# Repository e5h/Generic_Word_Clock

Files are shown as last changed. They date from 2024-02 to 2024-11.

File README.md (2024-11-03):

# Generic Word Clock

## Summary

This repository contains the mechanical, electrical, and software components for a generic and customizable word clock.

All of these components can be used together to create a personalized version, or they can be used interchangeably with existing word clocks and controllers.

This is based on the original word clock project I did in 2017 ([Instructables](https://www.instructables.com/Minimalist-3D-Printed-RGB-Word-Clock/), [GitHub](https://github.com/e5h/Word-Clock)). I created an additional mechanical word clock meant to use much cheaper and easier to assemble LED strips ([Thingiverse](https://www.thingiverse.com/thing:3011627)) based on initial feedback, but both versions were lacking.

This "Generic" version is meant to be a direct replacement and upgrade for both. There is a custom controller based on an ESP32C3 module, much better software, and a more customizable mechanical design which includes a script to automatically generate a clock face with any installed font and combination of characters.

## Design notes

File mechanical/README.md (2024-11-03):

# Word Clock Mechanical Components (WIP)

## Summary

<div style="display: flex; gap: 0px;">
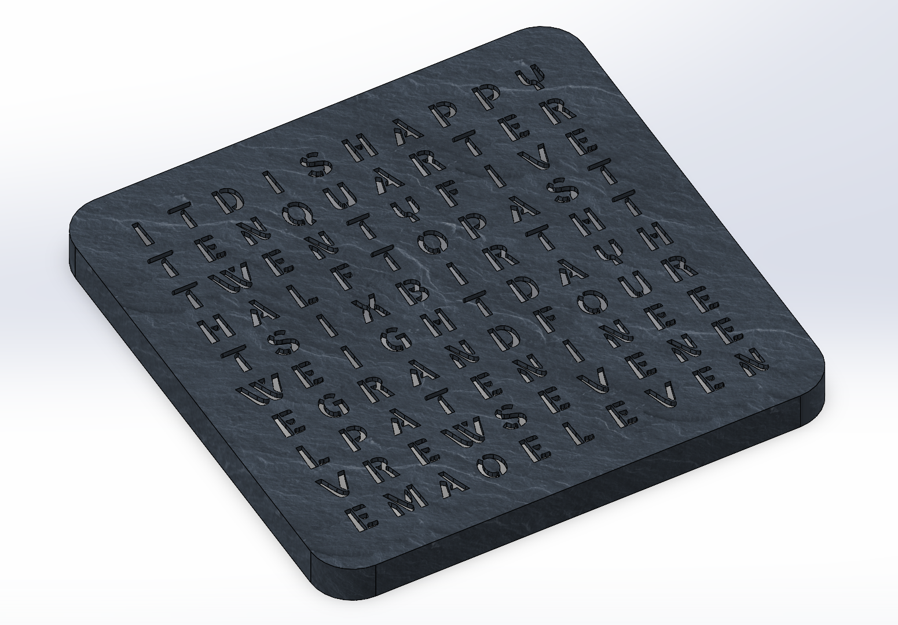
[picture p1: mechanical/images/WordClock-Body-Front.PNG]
Controller Front
  
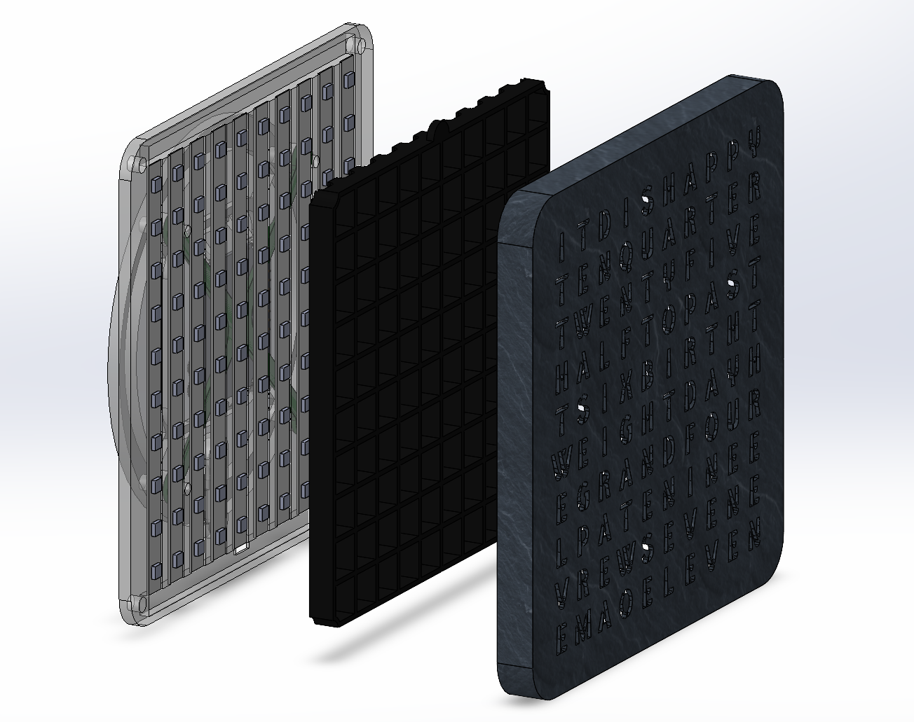
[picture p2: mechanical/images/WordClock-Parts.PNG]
  
</div>

<div style="display: flex; gap: 0px;">
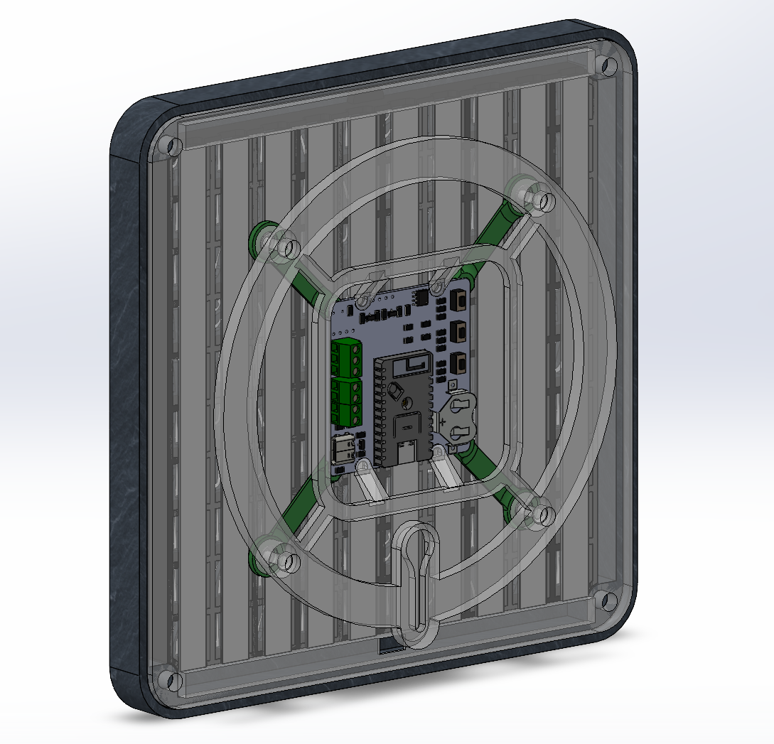
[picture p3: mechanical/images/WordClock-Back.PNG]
  
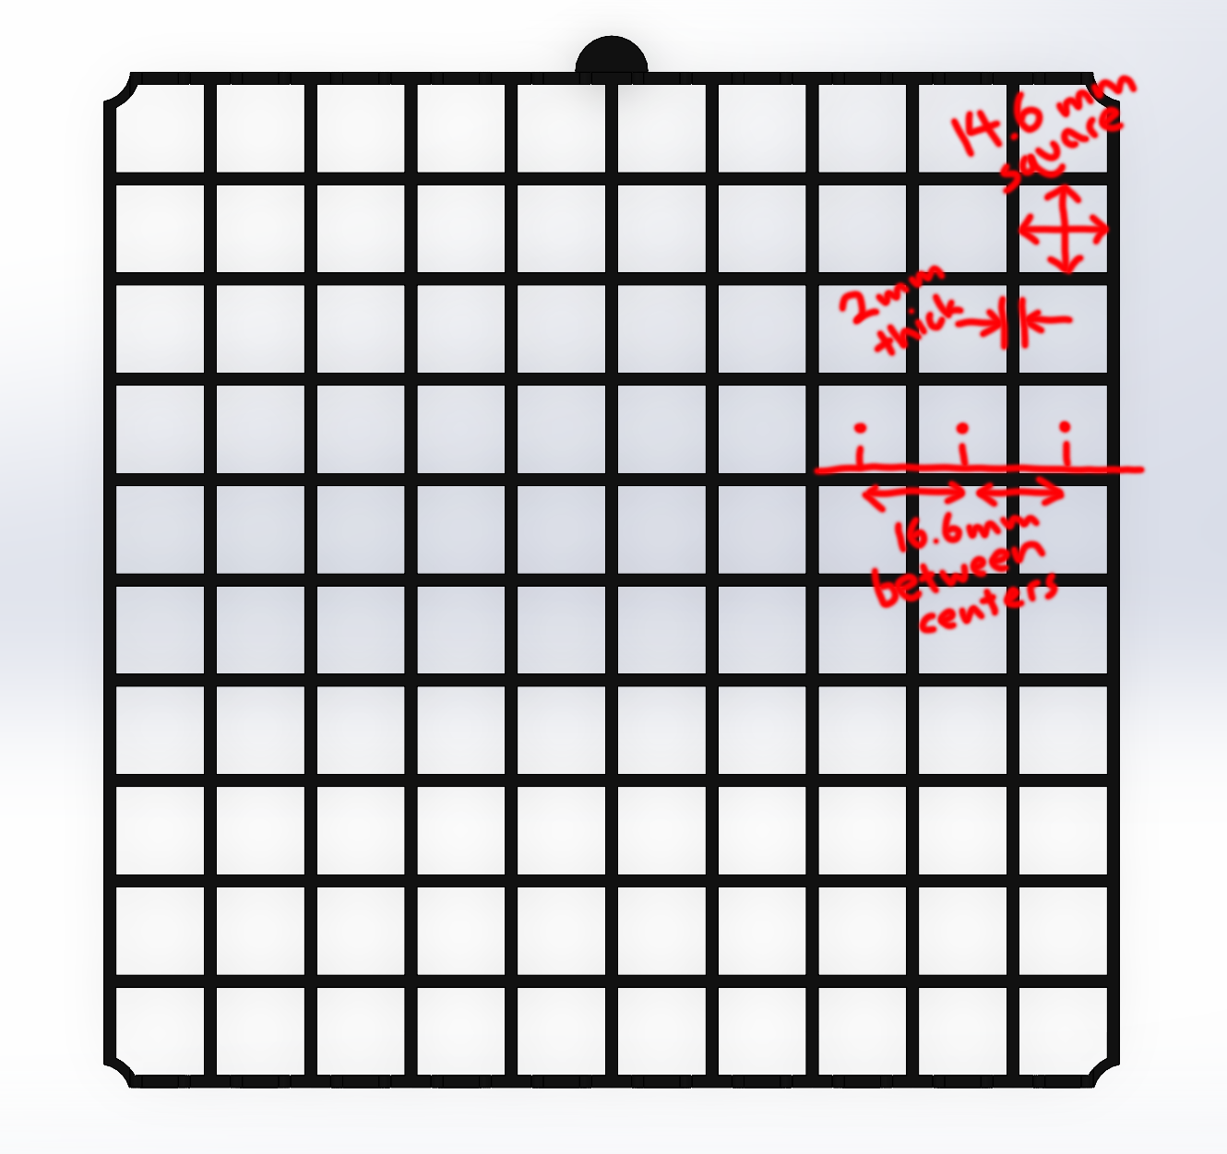
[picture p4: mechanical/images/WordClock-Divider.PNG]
  
</div>

The word clock uses a 3D printed body, with an RGB LED strip cut into pieces and glued to a back plate.

## Required Parts

| Part | Qnty. | Description | Supplier |
| --- |---| --- | --- |
| LED Strip | 1 | WS2812B (or similar) 60 LED / meter strip | [Amazon #1](https://www.amazon.ca/BTF-LIGHTING-Individual-Addressable-60Pixels-Non-Waterproof/dp/B088BPGMXB), [Amazon #2](https://www.amazon.ca/gp/product/B014R5PC42) |
| M3 Heat Set Nuts | 4 | Brass threaded nuts, buy a kit | [Amazon #3](https://www.amazon.ca/Assortment-Premium-Threaded-Embedment-Printing/dp/B0CTDBXGCF) |
| M4 Heat Set Nuts | 4 | Brass threaded nuts, buy a kit | [Amazon #3](https://www.amazon.ca/Assortment-Premium-Threaded-Embedment-Printing/dp/B0CTDBXGCF) |
| M3x8 Screw | 4 | Machine screw, any will do | [Amazon #4](https://www.amazon.ca/Hilitchi-510-Pcs-Button-Socket-Assortment/dp/B073SWNV5N) |
| M4x8 Screw | 4 | Button cap, but any will do | [Amazon #4](https://www.amazon.ca/Hilitchi-510-Pcs-Button-Socket-Assortment/dp/B073SWNV5N) |
| Hot Glue | n/a | For the LED strips / strain relief | n/a |
| Solder | n/a | Any | n/a |
| Wire | n/a | 3 conductor wire for LED strip to controller, 1 conductor for connections | n/a |
| USB-C Charging Cable | 1 | Slim right angle cable works best | [Amazon #5](https://www.amazon.ca/Agtray-4-Pack-Braided-Compatible-Samsung/dp/B0B6B7NK35) |
| USB Power Supply | 1 | \>5W properly rated supply | [Digikey](https://www.digikey.ca/en/products/detail/qualtek/QFWC-10-05/9771106) |

## 3D Printing

Note: Using a translucent filament color for the back panel and mount causes a nice backlight / glow effect on the mounting surface.

Note: Using a textured print plate will apply the textures to the clock face.

* Choose a darker filament for the clock body (or print solid infill) to prevent light transmission.
* Print the divider in black filament, or another color with zero transmission at 2mm thickness.
* Material does not matter, PLA or PETG work fine.
* Use a smaller nozzle (0.4mm or less) for the clock body to preserve detail on the clock face.

## Running The Clock Creation Script

### Requirements

1. Install [OpenSCAD](https://openscad.org/downloads.html) on your computer.
   1. On Windows, ensure the installed folder is added to the system %PATH% variable.
2. Install Python on your computer
3. Install a compatible stencil font on your computer.
   1. On Windows, you need to right click "Install For All Users" for OpenSCAD to have access to it.
   2. There are two stencil fonts (free for all use) included in the `/free_fonts` folder.

### Generating

1. Modify the `make_clock_body.txt` file to reflect your clock configuration:
   1. (TODO: unsupported) Add the font
   2. (TODO: unsupported) Add the text size
   3. Add the character layout
2. Run the `make_clock.py` script using Python and wait for completion.
3. Use the `Custom_Body.stl` file as your clock body.

#### Troubleshooting

All of the requirements need to be satisfied. The scripts do not perform sophisticated error checking and may not provide useful debug messages.

## DIY / Custom Solution

Creating a custom clock body (or using an existing one) is completely supported.

(TODO: more info)

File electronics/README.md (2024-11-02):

# Word Clock Electronics

## Summary

<div style="display: flex; gap: 10px;">
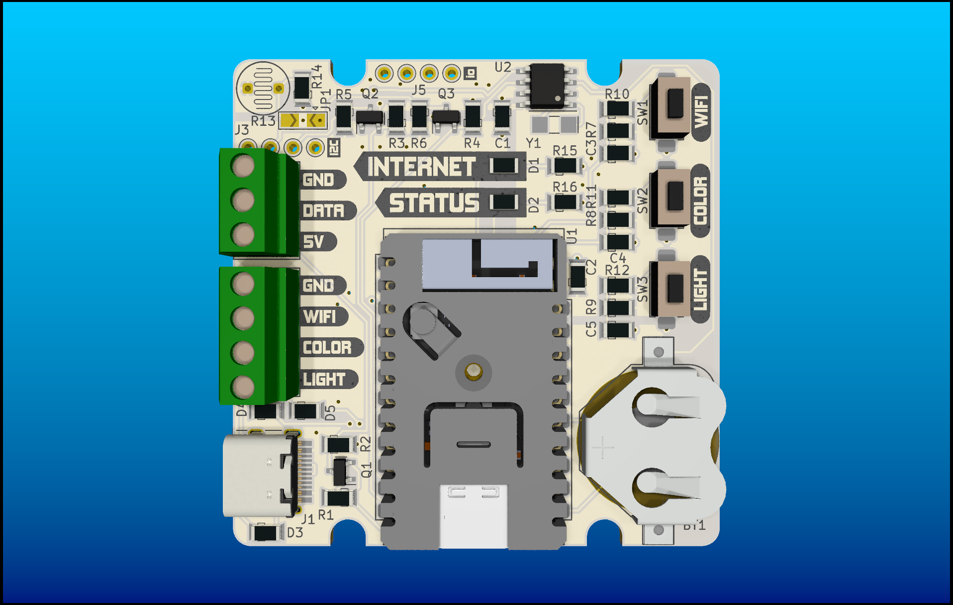
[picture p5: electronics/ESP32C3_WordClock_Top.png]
Controller Front
  
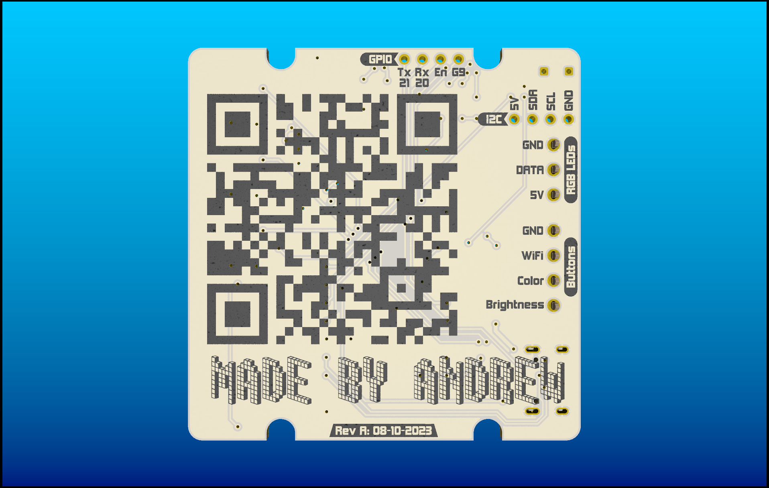
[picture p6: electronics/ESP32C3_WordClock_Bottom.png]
Controller Back
  
</div>

The word clock is powered by a custom ESP32-C3 based controller, using a PCF85263A real time clock module and a CR1632 backup battery.

The board was designed to use inexpensive parts, and has a small form factor which is inexpensive to get manufactured by online PCB fabricators. All components can be soldered by hand, and the back is unpopulated which allows using a hotplate and solder paste.

## Bill of Materials

| Ref | Type | Qnty | Part Number | Part Description | Supplier |
| --- | --- | ---- | --- | --- | ---|
| BT1 | Battery Holder  | 1 | 3012TR | CR1632 battery holder | [Digikey](https://www.digikey.ca/en/products/detail/keystone-electronics/3012TR/1978698) |
| C1 | Capacitor | 1 | 0.1uF-1uF | 0603-1206 X7R capacitor | |
| C2 | Capacitor | 1 | 0.1uF-1uF | 0603-1206 X7R capacitor | |
| C3, C4, C5 | Capacitor | 3 | 0.1uF | 0603-1206 X7R capacitor | |
| D1 | LED | 1 | SMD LED | 0603-1206 SMD LED | |
| D2 | LED | 1 | SMD LED | 0603-1206 SMD LED | |
| D3, D4, D5 | Diode | 3 | CUS520,H3F | External button protection diode | [Digikey](https://www.digikey.ca/en/products/detail/toshiba-semiconductor-and-storage/CUS520-H3F/5114303) |
| J1 | USB-C Conn. | 1 | USB4105-GF-A | USB_C_Receptacle_USB2.0 | [Digikey](https://www.digikey.ca/en/products/detail/gct/USB4105-GF-A/11198441) |
| J2 | Screw Terminal  | 1 | EBWA-03-A | External RGB LED connector | [Digikey](https://www.digikey.ca/en/products/detail/adam-tech/EBWA-03-A/9830974) |
| J3 | Empty Headers | 1 | n/a | 2.54mm external I2C breakout | |
| J4 | Screw Terminal  | 2 | EBWA-02-A | External buttons connector | [Digikey](https://www.digikey.ca/en/products/detail/adam-tech/EBWA-02-A/9830631) |
| J5 | Empty Headers | 1 | n/a | 2.54mm GPIO breakout | |
| JP1 | Jumper | 1 | n/a | Brightness select jumper | |
| Q1, Q2, Q3 | N-MOSFET | 3 | DMG2302UKQ-7 | Level shifter mosfet | [Digikey](https://www.digikey.ca/en/products/detail/diodes-incorporated/DMG2302UKQ-7/9769911) |
| R1, R2 | Resistor | 2 | 2.2kR | 0603-1206 SMD resistor, signal pullup | |
| R3, R5 | Resistor | 2 | 2.2kR | 0603-1206 SMD resistor, signal pullup | |
| R4, R6 | Resistor | 2 | 2.2kR | 0603-1206 SMD resistor, signal pullup | |
| R7, R8, R9, R14  | Resistor | 4 | 10kR | 10kR 0603-1206 SMD resistor | |
| R10, R11, R12 | Resistor | 3 | 1kR | 1kR 0603-1206 SMD resistor | |
| R13 | Photoresistor | 1 | varies | Generic THT photoresistor | |
| R15, R16 | Resistor | 2 | varies | LED resistors, size to D1 and D2 | |
| SW1 | Button | 1 | PTS636 SL43 SMTR LFS | WIFI push button | [Digikey](https://www.digikey.ca/en/products/detail/c-k/PTS636-SL43-SMTR-LFS/10071722) |
| SW2 | Button | 1 | PTS636 SL43 SMTR LFS | Color push button | [Digikey](https://www.digikey.ca/en/products/detail/c-k/PTS636-SL43-SMTR-LFS/10071723) |
| SW3 | Button | 1 | PTS636 SL43 SMTR LFS | Brightness push button | [Digikey](https://www.digikey.ca/en/products/detail/c-k/PTS636-SL43-SMTR-LFS/10071722) |
| U1 | Microcontroller | 1 | K056 | M5Stamp ESP32C3 module | [Digikey](https://www.digikey.ca/en/products/detail/m5stack-technology-co-ltd/K056/15667527) |
| U2 | RTC | 1 | PCF85263AT/AJ | Real time clock | [Digikey](https://www.digikey.ca/en/products/detail/nxp-usa-inc/PCF85263AT-AJ/5170041) |
| Y1 | Crystal | 1 | CM315D32768HZFT | 32.768kHz 12.5pF crystal | [Digikey](https://www.digikey.ca/en/products/detail/citizen-finedevice-co-ltd/CM315D32768HZFT/5970266) |

### Notes

- The footprints on the board for simple components are designed to work for 0603, 0805, and 1206 footprints (0402 may work for the brave). There are no specific part numbers listed.
- The resistor values for the LEDs, photoresistor, and the signal pullups can all be modified depending on need. 2.2kR for the signal pullups works well.

## DIY / Custom Solution

The firmware will work for any custom board (possibly a breadboard too) as long as the connections are the same as those listed in the schematic.

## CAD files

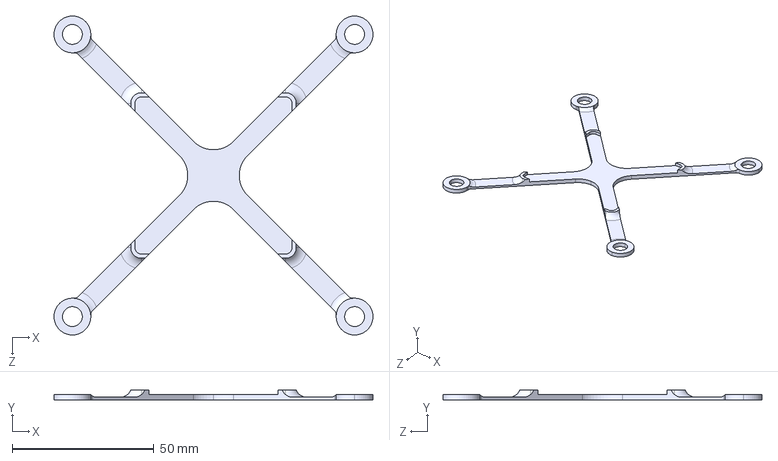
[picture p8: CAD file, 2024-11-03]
mechanical/Generic_Support_BoardHolder.STEP
112.6 x 3.50 x 112.6 mm

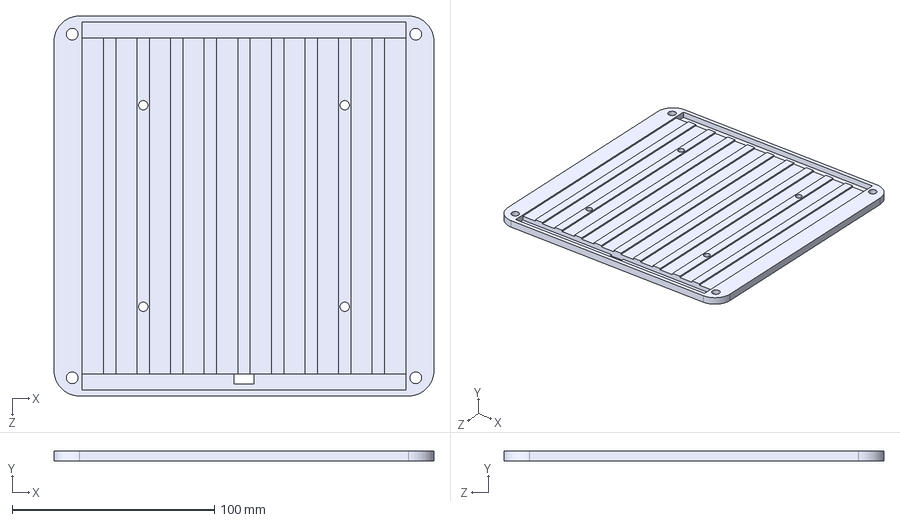
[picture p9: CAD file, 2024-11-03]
mechanical/Generic_Backplate.STEP
187.8 x 5.00 x 187.8 mm

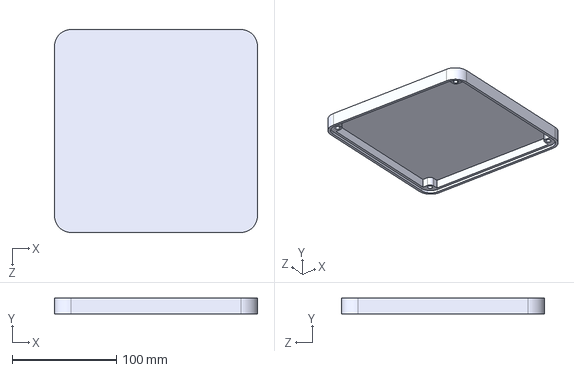
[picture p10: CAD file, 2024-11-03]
mechanical/Generic_Body_NoText.STEP
194.6 x 15.0 x 194.6 mm

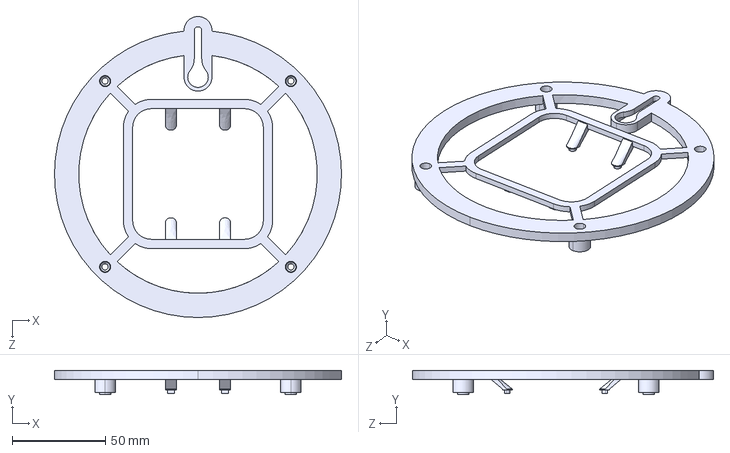
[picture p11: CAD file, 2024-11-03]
mechanical/Generic_Support_WallMount.STEP
153.9 x 13.0 x 161.4 mm

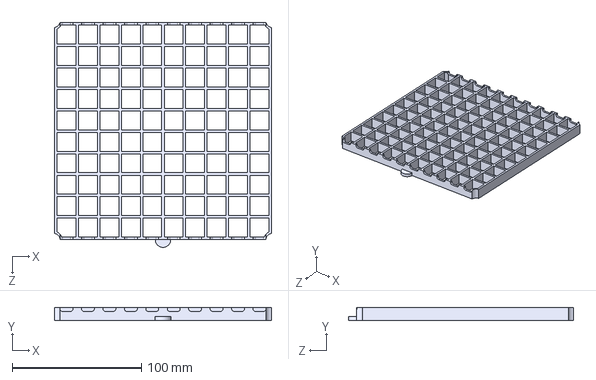
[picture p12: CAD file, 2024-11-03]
mechanical/Generic_Divider.STEP
168.0 x 10.0 x 174.0 mm

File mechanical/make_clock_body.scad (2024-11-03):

/* Variables */

// This is a default layout. Override it with a script.
ARG_clock_layout = [
  ["I", "T", "U", "I", "S", "J", "A", "X", "M", "Y"],
  ["T", "W", "E", "N", "T", "Y", "H", "A", "L", "F"],
  ["H", "A", "P", "P", "Y", "H", "F", "I", "V", "E"],
  ["T", "E", "N", "Q", "U", "A", "R", "T", "E", "R"],
  ["T", "O", "P", "A", "S", "T", "B", "D", "A", "Y"],
  ["O", "N", "E", "F", "O", "U", "R", "T", "W", "O"],
  ["F", "I", "V", "E", "S", "I", "X", "T", "E", "N"],
  ["T", "H", "R", "E", "E", "S", "E", "V", "E", "N"],
  ["T", "W", "E", "L", "V", "E", "I", "G", "H", "T"],
  ["N", "I", "N", "E", "L", "E", "V", "E", "N", "J"]
];

/*
Requires a stencil-type font (no closed off areas)

Some good options:
"CF StencilOrama" (personal use only)
"Crevice Stencil" (personal use only)
"Qawine Again" (personal use only)
"WC Wunderbach BTA"
"Secrets Stencil"
*/
ARG_font = "WC Wunderbach BTA";
ARG_font_size = 12;

// Total width of the body (square)
clock_width = 194.6;//mm

// Thickness of the body
clock_thickness = 15.0;//mm

// Total width of the divider (square)
divider_width = 168.0;//mm

// Thickness of the divider walls
divider_wall_thickness = 2.0;//mm

// Spacing between characters
char_spacing = 16.6;//mm

// Character bound box
char_bound_box = 14.6;//mm

// Movement constants
text_cut_slop = 5;//mm

move_clock_x = -clock_width/2;
move_clock_y = clock_thickness;
move_clock_z = -clock_width/2;

move_all_text_offset = divider_wall_thickness + char_bound_box/2;
move_all_text_x = move_all_text_offset - (divider_width/2);
move_all_text_y = clock_thickness - text_cut_slop;
move_all_text_z = (divider_width/2) - move_all_text_offset;

/* Parts */

// Blank clock body
module blank_clock_body()
{
  translate([move_clock_x, move_clock_y, move_clock_z])
  {
    mirror([0, 1, 0])
    {
      import("Generic_Body_NoText.STL");
    }
  }
}

// Individual extruded character
module extruded_char(char)
{
  linear_extrude(height = clock_thickness + text_cut_slop)
  {
    text(
      char,
      font = ARG_font,
      size = min(ARG_font_size, char_bound_box - 2),
      halign = "center",
      valign = "center"
    );
  }
}

// Grid of all characters
module extruded_clock_chars()
{
  for (row = [0 : len(ARG_clock_layout) - 1])
  {
    for (col = [0 : len(ARG_clock_layout[row]) - 1])
    {
      translate([col*char_spacing, -row*char_spacing, 0])
      {
        extruded_char(ARG_clock_layout[row][col]);
      }
    }
  }
}

// The clock characters object
module clock_chars()
{
  translate([move_all_text_x, move_all_text_y, move_all_text_z])
  {
    rotate([90, 0, 0])
    {
      extruded_clock_chars();
    }
  }
}


/* Operations */

// Subtracting a text grid from the blank clock body
difference()
{
  // Blank clock body
  blank_clock_body();
  // Text object
  clock_chars();
}

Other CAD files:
mechanical/Generic_Body_NoText.STL

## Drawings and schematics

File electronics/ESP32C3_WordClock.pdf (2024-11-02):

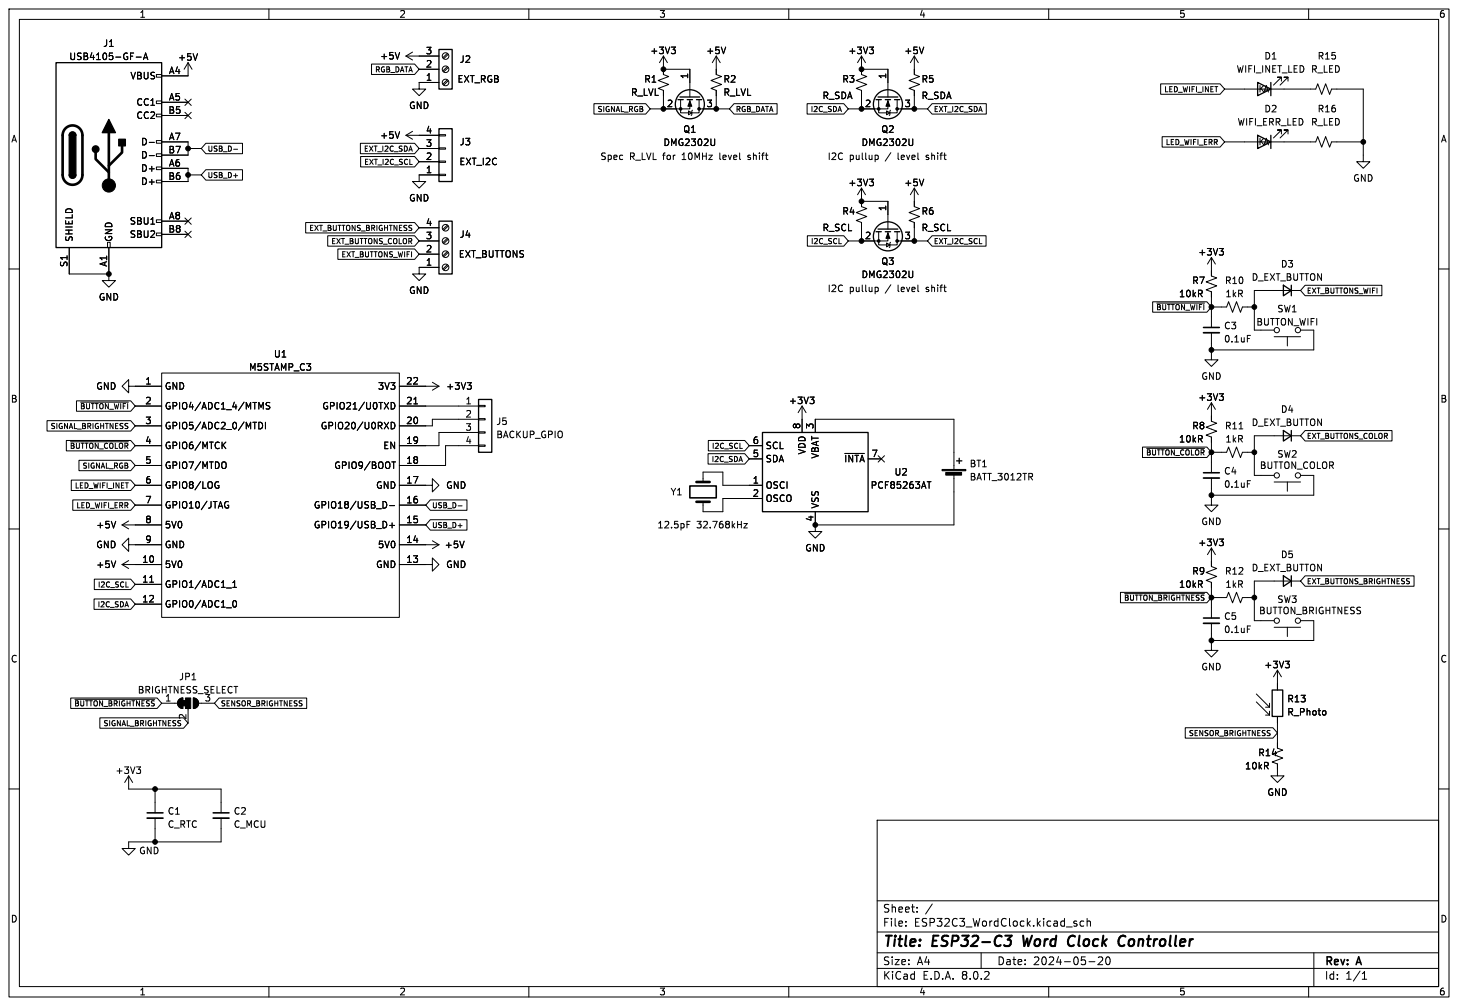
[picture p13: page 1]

Spec R_LVL for 10MHz level shift

4 SDA 5 SCL 6 ~{INTA} VDD 7

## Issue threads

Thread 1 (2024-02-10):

Add button functionality

e5h, 2024-02-10:
Read from the four buttons on the controller board, and support additional features:

- Abstracted button read (interrupts, i2c expander, gpio)
- Per-button state machine supporting press, hold, repeat
- Queue messaging according to pub/sub architecture

e5h, 2024-02-11:
Requires #6 to be completed before the send functionality can be added

Closed 2024-02-18.

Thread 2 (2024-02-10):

Implement real time clock

e5h, 2024-02-10:
Need to write a driver and functions for the embedded PCF8526 real time clock.

- Get time, set time
- Test battery backup
- Use NVS and timestamps to test for dead battery

e5h, 2024-05-21:
Major functionality is implemented, but needs to be tested to ensure it works with the time library, and with the hardware.

1. Ensure the conversions to and from timestamp structures are correct
2. Ensure the i2c bus is working correctly
3. Ensure the RTC has time set properly
4. Ensure the RTC battery backup is working as expected

e5h, 2024-07-14:
See comment for #[6db955e](https://github.com/e5h/Generic_Word_Clock/commit/6db955ef784d77e764c517fdd5c030156d678ece)

Getting time and setting time works, and the RTC is functional. All registers have been defined if more complex logic is needed in the future. NVS is unnecessary for testing a dead battery, simply evaluate if the RTC has the default value stored on boot.

Further changes will be done in higher-level feature tickets.

e5h, 2024-07-14:
Merged in PR #10.

Closed 2024-07-14.

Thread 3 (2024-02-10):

Implement networking

e5h, 2024-02-10:
Need to implement a number of networking features:

- Wifi AP, using dns redirect to a hosted html page with various settings (separate issue)
- Wifi STA, periodically access ntp server to calibrate / update the RTC
- Fault tolerant state machines for wifi, ntp, http server
- (?) html page when connected as sta to wifi?

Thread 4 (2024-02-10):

Create i2c access controls

e5h, 2024-02-10:
Esp-idf does not have access controls for multiple devices using the i2c bus. Find an existing solution, or implement an access lock to prevent bus conflicts.

e5h, 2024-07-14:
Note: this is no longer true, the new version of ESP-IDF which I have upgraded to (IDF 5.2+) contain a new I2C driver (https://docs.espressif.com/projects/esp-idf/en/v5.2.2/esp32/api-reference/peripherals/i2c.html). This resolves the access control issues with the legacy driver, so there is no longer a need for i2c_manager.

Closed 2024-05-20.

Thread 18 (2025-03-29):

Add event system / architecture

e5h, 2025-03-29:
Functionality partially exists with the messaging system. There are a few different tasks running concurrently, and they all have unique state machines which should be influenced by the idea of "events" generating from other tasks.

Example:

1. Device task detects "wifi button" held, generates a "wifi button held" event
2. Network task receives "wifi button held" event, attempts to connect to wifi as sta
3. Network task detects successful connection, generates a "wifi sta connected" event
4. Device task should receive a "wifi sta connected" event, and toggle the "wifi LED"
5. Display task can indicate a wifi connection event (?)

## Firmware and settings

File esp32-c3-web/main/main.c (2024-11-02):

/*~*~*~*~*~*~*~*~*~*~*~*~*~*~*~*~*~*~*~*~*~*~*~*~*~*~*~*~*~*~*~*~*~*~*~*~*~*~*~*~
 * NAME:
 *      main.c
 *
 * PURPOSE:
 *      This is the main file for running the generic word clock.
 *
 * DEPENDENCIES:
 *      lib_includes.h
 *
 *~*~*~*~*~*~*~*~*~*~*~*~*~*~*~*~*~*~*~*~*~*~*~*~*~*~*~*~*~*~*~*~*~*~*~*~*~*~*~*
 * (C) Andrew Bright 2023, github.com/e5h
 *~*~*~*~*~*~*~*~*~*~*~*~*~*~*~*~*~*~*~*~*~*~*~*~*~*~*~*~*~*~*~*~*~*~*~*~*~*~*~*/

/*~*~*~*~*~*~*~*~*~*~*~*~*~*~*~*~*~*~*~*~*~*~*~*~*~*~*~*~*~*~*~*~*~*~*~*~*~*~*~*/
/*][ Include Files ][*~*~*~*~*~*~*~*~*~*~*~*~*~*~*~*~*~*~*~*~*~*~*~*~*~*~*~*~*~*/
/*~*~*~*~*~*~*~*~*~*~*~*~*~*~*~*~*~*~*~*~*~*~*~*~*~*~*~*~*~*~*~*~*~*~*~*~*~*~*~*/

#include <stdio.h>
#include "lib_includes.h"
#include "lib_messaging.h"

#include "rgb_rmt.h"
#include "cfg_clock.h"
#include "rtc.h"

#include "task_display.h"
// task device
// task network

#include "esp_timer.h"
#include "nvs_flash.h"

/*~*~*~*~*~*~*~*~*~*~*~*~*~*~*~*~*~*~*~*~*~*~*~*~*~*~*~*~*~*~*~*~*~*~*~*~*~*~*~*/
/*][ LOCAL : Constants and Types ][*~*~*~*~*~*~*~*~*~*~*~*~*~*~*~*~*~*~*~*~*~*~*/
/*~*~*~*~*~*~*~*~*~*~*~*~*~*~*~*~*~*~*~*~*~*~*~*~*~*~*~*~*~*~*~*~*~*~*~*~*~*~*~*/

typedef enum{
    FLAG_1_MS           = 0x01, /* Flag set on 1ms timer callback */
    FLAG_10_MS          = 0x02, /* Flag set on 10ms timer callback */
    FLAG_100_MS         = 0x04, /* Flag set on 100ms timer callback */
    FLAG_1_SEC          = 0x08, /* Flag set on 1s timer callback */
} E_THREAD_FLAG;

/*~*~*~*~*~*~*~*~*~*~*~*~*~*~*~*~*~*~*~*~*~*~*~*~*~*~*~*~*~*~*~*~*~*~*~*~*~*~*~*/
/*][ LOCAL : Variables ][*~*~*~*~*~*~*~*~*~*~*~*~*~*~*~*~*~*~*~*~*~*~*~*~*~*~*~*/
/*~*~*~*~*~*~*~*~*~*~*~*~*~*~*~*~*~*~*~*~*~*~*~*~*~*~*~*~*~*~*~*~*~*~*~*~*~*~*~*/

/* ESP event groups (flags) */
EventGroupHandle_t heartbeat_flags;

/* ESP timer handles */
esp_timer_handle_t timer_handle_1ms;
esp_timer_handle_t timer_handle_10ms;
esp_timer_handle_t timer_handle_100ms;
esp_timer_handle_t timer_handle_1sec;

/* FreeRTOS task handles */
TaskHandle_t h_task_heartbeat;

/* Order and request queues */
QueueHandle_t q_heartbeat_task;

// Clock configuration
static CLOCK_CONFIG clock_config_s;

/*~*~*~*~*~*~*~*~*~*~*~*~*~*~*~*~*~*~*~*~*~*~*~*~*~*~*~*~*~*~*~*~*~*~*~*~*~*~*~*/
/*][ LOCAL : Function Prototypes ][*~*~*~*~*~*~*~*~*~*~*~*~*~*~*~*~*~*~*~*~*~*~*/
/*~*~*~*~*~*~*~*~*~*~*~*~*~*~*~*~*~*~*~*~*~*~*~*~*~*~*~*~*~*~*~*~*~*~*~*~*~*~*~*/

/*~*~*~*~*~*~*~*~*~*~*~*~*~*~*~*~*~*~*~*~*~*~*~*~*~*~*~*~*~*~*~*~*~*~*~*~*~*~*~*/
/*][ Function Definitions ][~*~*~*~*~*~*~*~*~*~*~*~*~*~*~*~*~*~*~*~*~*~*~*~*~*~*/
/*~*~*~*~*~*~*~*~*~*~*~*~*~*~*~*~*~*~*~*~*~*~*~*~*~*~*~*~*~*~*~*~*~*~*~*~*~*~*~*/

/**===< local >================================================================
 * NAME:
 *      nvs_save_clock_config() - saves the current clock configuration
 *
 * SUMMARY:
 *      Takes all of the clock configuration values and saves them to non
 *      volatile storage.
 *
 * INPUT REQUIREMENTS:
 *      ---
 *
 * OUTPUT GUARANTEES:
 *      Returns an enum status (fail <= 0, success > 0)
 **===< local >================================================================*/
static STATUS_E nvs_save_clock_config( CLOCK_CONFIG* new_config_s )
{
    nvs_handle_t nvs_handle;
    size_t config_size = sizeof( CLOCK_CONFIG );

    esp_err_t err;
    STATUS_E status_e = STATUS_OK;

    // Check for differences to reduce memory wear
    if( memcmp( new_config_s, &clock_config_s, config_size ) == 0 )
    {
        return STATUS_NO_CHANGE; // No change
    }

    // TODO: Sanity check the values

    err = nvs_open( "clock", NVS_READWRITE, &nvs_handle );
    if( err != ESP_OK )
    {
        ESP_LOGE("nvs_save_clock_config", "Could not open NVS! (%s)", esp_err_to_name(err));
        return STATUS_ERR;
    }

    err = nvs_set_blob( nvs_handle, "clockconfig", new_config_s, config_size );
    if( err != ESP_OK )
    {
        ESP_LOGE("nvs_save_clock_config", "Could not write to NVS! (%s)", esp_err_to_name(err));
        return STATUS_ERR;
    }

    err = nvs_commit( nvs_handle );
    if( err != ESP_OK )
    {
        ESP_LOGE("nvs_save_clock_config", "Could not save NVS! (%s)", esp_err_to_name(err));
        return STATUS_ERR;
    }

    nvs_close( nvs_handle );
    ESP_LOGW("nvs_save_clock_config", "Saved clock config to NVS.");
    ESP_LOGI("nvs_save_clock_config", "Saved time: ");
    // TODO: Convert the struct tm to a readable timestamp.

    clock_config_s = *new_config_s;

    return status_e;
}

/**===< local >================================================================
 * NAME:
 *      nvs_load_clock_config() - loads the current clock configuration
 *
 * SUMMARY:
 *      Loads all of the clock configuration values from the on-board non
 *      volatile storage.
 *
 * INPUT REQUIREMENTS:
 *      ---
 *
 * OUTPUT GUARANTEES:
 *      Returns an enum status (fail <= 0, success > 0)
 **===< local >================================================================*/
static STATUS_E nvs_load_clock_config( CLOCK_CONFIG* new_config_s )
{
    nvs_handle_t nvs_handle;
    size_t config_size = sizeof( CLOCK_CONFIG );

    esp_err_t err;
    STATUS_E status_e = STATUS_OK;

    err = nvs_open( "clock", NVS_READWRITE, &nvs_handle );
    if( err != ESP_OK )
    {
        ESP_LOGE("nvs_load_clock_config", "Could not open NVS! (%s)", esp_err_to_name(err));
        return STATUS_ERR;
    }

    err = nvs_get_blob( nvs_handle, "clockconfig", new_config_s, &config_size );
    if( err != ESP_OK )
    {
        ESP_LOGE("nvs_load_clock_config", "Could not read from NVS! (%s)", esp_err_to_name(err));
        return STATUS_ERR;
    }

    err = nvs_commit( nvs_handle );
    if( err != ESP_OK )
    {
        ESP_LOGE("nvs_load_clock_config", "Could not save NVS! (%s)", esp_err_to_name(err));
        return STATUS_ERR;
    }

    nvs_close( nvs_handle );
    ESP_LOGW("nvs_load_clock_config", "Loaded clock config from NVS.");
    ESP_LOGI("nvs_load_clock_config", "Loaded time: ");
    // TODO: Convert the struct tm to a readable timestamp.

    clock_config_s = *new_config_s;

    return status_e;
}

/*~*~*~*~*~*~*~*~*~*~*~*~*~*~*~*~*~*~*~*~*~*~*~*~*~*~*~*~*~*~*~*~*~*~*~*~*~*~*~*~
 * Timer callback - 1 ms
 *
 * DESCRIPTION:
 *      This function is called every 1 millisecond. The purpose is to wake
 *      certain tasks periodically by setting their task notification bits.
 *~*~*~*~*~*~*~*~*~*~*~*~*~*~*~*~*~*~*~*~*~*~*~*~*~*~*~*~*~*~*~*~*~*~*~*~*~*~*~*/
void timer_1ms_callback(void *param)
{
    TIMER_TickMsUpdate(); /* Updates the 1ms tick inside lib_timer */
    //xEventGroupSetBits( heartbeat_flags, FLAG_1_MS );
}

/*~*~*~*~*~*~*~*~*~*~*~*~*~*~*~*~*~*~*~*~*~*~*~*~*~*~*~*~*~*~*~*~*~*~*~*~*~*~*~*~
 * Timer callback - 10 ms
 *
 * DESCRIPTION:
 *      This function is called every 10 milliseconds. The purpose is to wake
 *      certain tasks periodically by setting their task notification bits.
 *~*~*~*~*~*~*~*~*~*~*~*~*~*~*~*~*~*~*~*~*~*~*~*~*~*~*~*~*~*~*~*~*~*~*~*~*~*~*~*/
void timer_10ms_callback(void *param)
{
    // Set event group bits
}

/*~*~*~*~*~*~*~*~*~*~*~*~*~*~*~*~*~*~*~*~*~*~*~*~*~*~*~*~*~*~*~*~*~*~*~*~*~*~*~*~
 * Timer callback - 100 ms
 *
 * DESCRIPTION:
 *      This function is called every 100 milliseconds. The purpose is to wake
 *      certain tasks periodically by setting their task notification bits.
 *~*~*~*~*~*~*~*~*~*~*~*~*~*~*~*~*~*~*~*~*~*~*~*~*~*~*~*~*~*~*~*~*~*~*~*~*~*~*~*/
void timer_100ms_callback(void *param)
{
    xEventGroupSetBits(heartbeat_flags, FLAG_100_MS );
}

/*~*~*~*~*~*~*~*~*~*~*~*~*~*~*~*~*~*~*~*~*~*~*~*~*~*~*~*~*~*~*~*~*~*~*~*~*~*~*~*~
 * Timer callback - 1 sec
 *
 * DESCRIPTION:
 *      This function is called every 1 second. The purpose is to wake
 *      certain tasks periodically by setting their task notification bits.
 *~*~*~*~*~*~*~*~*~*~*~*~*~*~*~*~*~*~*~*~*~*~*~*~*~*~*~*~*~*~*~*~*~*~*~*~*~*~*~*/
void timer_1sec_callback(void *param)
{
    xEventGroupSetBits(heartbeat_flags, FLAG_1_SEC );
}

/*~*~*~*~*~*~*~*~*~*~*~*~*~*~*~*~*~*~*~*~*~*~*~*~*~*~*~*~*~*~*~*~*~*~*~*~*~*~*~*~
 * TASK: task_heartbeat
 * PRIO: 2 - default priority (runs constantly)
 *
 * DESCRIPTION:
 *      This task handles periodic behaviour, primarily for testing.
 *
 *~*~*~*~*~*~*~*~*~*~*~*~*~*~*~*~*~*~*~*~*~*~*~*~*~*~*~*~*~*~*~*~*~*~*~*~*~*~*~*/
void task_heartbeat(void* params )
{
    char* LOG_TAG = "task_heartbeat";

    EventBits_t new_msg_flag_s = 0x80u;
    MESSAGE_CONTENT_T rec_msg;
    MESSAGE_RECEIVER_T inbox = {
            &heartbeat_flags,
            new_msg_flag_s,
            q_heartbeat_task
    };

    EventBits_t flags_to_wait;
    flags_to_wait = FLAG_100_MS | FLAG_1_SEC | new_msg_flag_s;

    UINT8 active_leds[10] = {0}; // Index of which LEDs are active
    
    UINT8 colorIndex_UC = COLOR_Cyan;
    RGB_COLOR_PCT led_color = RGB_LED_default_colors_S[ colorIndex_UC ];

    MESSAGING_subscribe_to_topic(MSG_BUTTONS, &inbox);

    // Temporarily here for testing
    BUTTON_init();

    while(1)
    {
        /* Wait for any of the flags to be set (wait all = false, auto clear = false) */
        xEventGroupWaitBits(heartbeat_flags, flags_to_wait, false, false, portMAX_DELAY );

        /* New message */
        if(xEventGroupGetBits(heartbeat_flags) & new_msg_flag_s)
        {
            xQueueReceive(q_heartbeat_task, &rec_msg, 0);

            if(rec_msg.topic_e == MSG_BUTTONS)
            {
                CHAR p_button_str_c[40];
                memset(p_button_str_c, 0, sizeof(p_button_str_c));
                BUTTON_event_to_string(&rec_msg.btn_event_s, p_button_str_c, sizeof(p_button_str_c)-1);

                ESP_LOGI(LOG_TAG, "Button message: %s", p_button_str_c);

                // If the "light" button was just pressed, toggle the "status" LED
                if(BUTTON_check_event(&rec_msg.btn_event_s, BTN_LIGHT, BTN_PRESS_RELEASED))
                {
                    ESP_LOGI(LOG_TAG, "Toggling the 'STATUS' LED.");
                    gpio_set_level(GPIO_NUM_10, gpio_get_level(GPIO_NUM_10) ? 0 : 1);
                }

                // If the "light" button was just held, toggle the "wifi" LED
                if(BUTTON_check_event(&rec_msg.btn_event_s, BTN_LIGHT, BTN_HOLD_RELEASED))
                {
                    ESP_LOGI(LOG_TAG, "Toggling the 'INTERNET' LED.");
                    gpio_set_level(GPIO_NUM_8, gpio_get_level(GPIO_NUM_8) ? 0 : 1);
                }
            }

            /* Clear the message flag if there are none left */
            if(uxQueueMessagesWaiting(q_heartbeat_task) == 0)
            {
                xEventGroupClearBits(heartbeat_flags, new_msg_flag_s);
            }
        }

        /* FLAG_100_MS - update */
        if(xEventGroupGetBits(heartbeat_flags ) & FLAG_100_MS )
        {
            // The button handler can be done via polling, or after detecting interrupts.
            // This can be done anywhere, currently here for testing.
            BUTTON_poll();
            if(BUTTON_update_state_machine() == STATUS_NEW_EVENT)
            {
                if(BUTTON_send_events_to_queue() >= STATUS_OK)
                {
                    ESP_LOGI(LOG_TAG, "Sent new button events to queue.");
                }
                else
                {
                    ESP_LOGE(LOG_TAG, "Failed to send new button events to queue!");
                }
            }

            /* Clear FLAG_100_MS */
            xEventGroupClearBits(heartbeat_flags, FLAG_100_MS );
        }

        /* FLAG_1_SEC - update */
        if(xEventGroupGetBits(heartbeat_flags ) & FLAG_1_SEC )
        {
            static UINT32 sec_count = 0;

            led_color = RGB_LED_default_colors_S[ colorIndex_UC ];

            CLOCK_TestWords( led_color );

            if( ++colorIndex_UC >= NUM_DEFAULT_COLORS )
            {
                colorIndex_UC = 0;
                CLOCK_UpdateTime(); // test a phrase
            }

            sec_count++;
            if(sec_count % 10 == 0)
            {
                struct tm rtc_time_s;
                if(RTC_get_time(&rtc_time_s) >= STATUS_OK)
                {
                    ESP_LOGI(LOG_TAG, "Retrieved RTC time: %s", asctime(&rtc_time_s));
                }
                else
                {
                    ESP_LOGE(LOG_TAG, "Failed to get time from RTC.");
                }
            }

            /* Clear FLAG_1_SEC */
            xEventGroupClearBits(heartbeat_flags, FLAG_1_SEC );
        }
    }
}

/*~*~*~*~*~*~*~*~*~*~*~*~*~*~*~*~*~*~*~*~*~*~*~*~*~*~*~*~*~*~*~*~*~*~*~*~*~*~*~*~
 * app_main
 *
 * DESCRIPTION:
 *      This acts as the initial setup of the device when powered on. It sets up
 *      all hardware peripherals, and begins each RTOS task.
 *~*~*~*~*~*~*~*~*~*~*~*~*~*~*~*~*~*~*~*~*~*~*~*~*~*~*~*~*~*~*~*~*~*~*~*~*~*~*~*/
void app_main(void)
{
    /* Hardware delays (capacitors, etc) */

    /* Set up event groups */
    heartbeat_flags = xEventGroupCreate();

    /* Set up queues */
    q_heartbeat_task = xQueueCreate( 10, sizeof(MESSAGE_CONTENT_T) );

    /* Set up other peripherals */
    RGB_LED_Init();
    RTC_init(PCF85263A_ADDR_7BIT);

    /* Initialize I2C driver */


    /* Set up timers */
    /* 1 ms timer */
    const esp_timer_create_args_t timer_args_1ms = {
        .callback = &timer_1ms_callback,
        .name = "1 ms timer"
    };
    ESP_ERROR_CHECK(esp_timer_create(&timer_args_1ms, &timer_handle_1ms));
    ESP_ERROR_CHECK(esp_timer_start_periodic(timer_handle_1ms, 1000));

    /* 10ms timer */
    const esp_timer_create_args_t timer_args_10ms = {
        .callback = &timer_10ms_callback,
        .name = "10 ms timer"
    };
    ESP_ERROR_CHECK(esp_timer_create(&timer_args_10ms, &timer_handle_10ms));
    ESP_ERROR_CHECK(esp_timer_start_periodic(timer_handle_10ms, 10000));

    /* 100ms timer */
    const esp_timer_create_args_t timer_args_100ms = {
        .callback = &timer_100ms_callback,
        .name = "100 ms timer"
    };
    ESP_ERROR_CHECK(esp_timer_create(&timer_args_100ms, &timer_handle_100ms));
    ESP_ERROR_CHECK(esp_timer_start_periodic(timer_handle_100ms, 100000));

    /* 1sec timer */
    const esp_timer_create_args_t timer_args_1sec = {
        .callback = &timer_1sec_callback,
        .name = "1 sec timer"
    };
    ESP_ERROR_CHECK(esp_timer_create(&timer_args_1sec, &timer_handle_1sec));
    ESP_ERROR_CHECK(esp_timer_start_periodic(timer_handle_1sec, 1000000));

    /* Set up interrupts */

    /* Set up tasks */
    xTaskCreate(&task_heartbeat, "RGB Led Task", 4096, NULL, 2, &h_task_heartbeat );

    /* GPIO settings */
    gpio_set_direction(GPIO_NUM_8, GPIO_MODE_INPUT_OUTPUT);
    gpio_set_direction(GPIO_NUM_10, GPIO_MODE_INPUT_OUTPUT);
}

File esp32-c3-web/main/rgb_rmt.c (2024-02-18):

/*~*~*~*~*~*~*~*~*~*~*~*~*~*~*~*~*~*~*~*~*~*~*~*~*~*~*~*~*~*~*~*~*~*~*~*~*~*~*~*~
 * NAME:
 *      rgb_rmt.c
 *
 * PURPOSE:
 *      This module is designed to provide simple functions to control RGB leds
 *      using the RMT peripheral of the ESP32.
 *
 * DEPENDENCIES:
 *      ---
 *
 *~*~*~*~*~*~*~*~*~*~*~*~*~*~*~*~*~*~*~*~*~*~*~*~*~*~*~*~*~*~*~*~*~*~*~*~*~*~*~*
 * (C) Andrew Bright 2023, github.com/e5h
 *~*~*~*~*~*~*~*~*~*~*~*~*~*~*~*~*~*~*~*~*~*~*~*~*~*~*~*~*~*~*~*~*~*~*~*~*~*~*~*/

/*~*~*~*~*~*~*~*~*~*~*~*~*~*~*~*~*~*~*~*~*~*~*~*~*~*~*~*~*~*~*~*~*~*~*~*~*~*~*~*/
/*][ Include Files ][*~*~*~*~*~*~*~*~*~*~*~*~*~*~*~*~*~*~*~*~*~*~*~*~*~*~*~*~*~*/
/*~*~*~*~*~*~*~*~*~*~*~*~*~*~*~*~*~*~*~*~*~*~*~*~*~*~*~*~*~*~*~*~*~*~*~*~*~*~*~*/

#include "rgb_rmt.h"
#include "cfg_clock.h"

/*~*~*~*~*~*~*~*~*~*~*~*~*~*~*~*~*~*~*~*~*~*~*~*~*~*~*~*~*~*~*~*~*~*~*~*~*~*~*~*/
/*][ LOCAL : Constants and Types ][*~*~*~*~*~*~*~*~*~*~*~*~*~*~*~*~*~*~*~*~*~*~*/
/*~*~*~*~*~*~*~*~*~*~*~*~*~*~*~*~*~*~*~*~*~*~*~*~*~*~*~*~*~*~*~*~*~*~*~*~*~*~*~*/

#define RGB_LED_PIN         WC_RGB_LED_PIN
#define RGB_LED_COUNT       WC_RGB_LED_COUNT
#define RGB_LED_TYPE        WC_RGB_LED_TYPE

/* Struct for an RGBLED encoder */
typedef struct{
    rmt_encoder_t       base;
    rmt_encoder_t       *byte_encoder;
    rmt_encoder_t       *copy_encoder;
    rmt_symbol_word_t   reset_code;
    INT32               encoder_state;
} RGB_LED_ENCODER;

/* Struct to hold a 24-bit RGB encoded color */
typedef struct __attribute__ ((packed)){
    UINT8 red_U8;
    UINT8 green_U8;
    UINT8 blue_U8;
} RGB_COLOR_24BIT;

/*~*~*~*~*~*~*~*~*~*~*~*~*~*~*~*~*~*~*~*~*~*~*~*~*~*~*~*~*~*~*~*~*~*~*~*~*~*~*~*/
/*][ LOCAL : Variables ][*~*~*~*~*~*~*~*~*~*~*~*~*~*~*~*~*~*~*~*~*~*~*~*~*~*~*~*/
/*~*~*~*~*~*~*~*~*~*~*~*~*~*~*~*~*~*~*~*~*~*~*~*~*~*~*~*~*~*~*~*~*~*~*~*~*~*~*~*/

// Gamma brightness lookup table <https://victornpb.github.io/gamma-table-generator>
// gamma = 2.00 steps = 101 range = 0-255
static const UINT8 gamma_lut[101] = {
     0,   0,   0,   0,   0,   1,   1,   1,   2,   2,   3,   3,   4,   4,   5,   6,
     7,   8,   8,   9,  10,  11,  13,  14,  15,  16,  18,  19,  20,  22,  23,  25,
    27,  28,  30,  32,  34,  36,  38,  40,  42,  44,  46,  48,  50,  53,  55,  57,
    60,  62,  65,  68,  70,  73,  76,  79,  82,  85,  88,  91,  94,  97, 100, 103,
   107, 110, 113, 117, 120, 124, 127, 131, 135, 139, 142, 146, 150, 154, 158, 162,
   167, 171, 175, 179, 184, 188, 192, 197, 201, 206, 211, 215, 220, 225, 230, 235,
   240, 245, 250, 255, 255 };

/* All known timing parameters for common RGB LEDs */
static const RGB_LED_TYPE_PARAMS RGB_LED_all_params_S[] = {
    [LED_WS2812_V1]   = { .pixel_sz_bytes = 3, .T0H = 0.35, .T1H = 0.70, .T0L = 0.80, .T1L = 0.60, .TRS =  50.0},
    [LED_WS2812B_V1]  = { .pixel_sz_bytes = 3, .T0H = 0.35, .T1H = 0.90, .T0L = 0.90, .T1L = 0.35, .TRS =  50.0},
    [LED_WS2812B_V2]  = { .pixel_sz_bytes = 3, .T0H = 0.40, .T1H = 0.85, .T0L = 0.85, .T1L = 0.40, .TRS =  50.0},
    [LED_WS2812B_V3]  = { .pixel_sz_bytes = 3, .T0H = 0.45, .T1H = 0.85, .T0L = 0.85, .T1L = 0.45, .TRS =  50.0},
    [LED_WS2813_V1]   = { .pixel_sz_bytes = 3, .T0H = 0.35, .T1H = 0.80, .T0L = 0.35, .T1L = 0.35, .TRS = 300.0},
    [LED_WS2813_V2]   = { .pixel_sz_bytes = 3, .T0H = 0.27, .T1H = 0.80, .T0L = 0.80, .T1L = 0.27, .TRS = 300.0},
    [LED_WS2813_V3]   = { .pixel_sz_bytes = 3, .T0H = 0.27, .T1H = 0.63, .T0L = 0.63, .T1L = 0.27, .TRS = 300.0},
    [LED_SK6812_V1]   = { .pixel_sz_bytes = 3, .T0H = 0.30, .T1H = 0.60, .T0L = 0.90, .T1L = 0.60, .TRS =  80.0},
    [LED_PI554FCH]    = { .pixel_sz_bytes = 3, .T0H = 0.30, .T1H = 0.60, .T0L = 0.90, .T1L = 0.60, .TRS =  80.0},
};

/* Definitions for default colors, (0.0 - 1.0) = (0 - 255) */
const RGB_COLOR_PCT RGB_LED_default_colors_S[] = {
    {.r = 1.0, .g = 0.0, .b = 0.0}, /* COLOR_Red */
    {.r = 1.0, .g = 0.5, .b = 0.0}, /* COLOR_Orange */
    {.r = 1.0, .g = 1.0, .b = 0.0}, /* COLOR_Yellow */
    {.r = 0.5, .g = 1.0, .b = 0.0}, /* COLOR_Lime */
    {.r = 0.0, .g = 1.0, .b = 0.0}, /* COLOR_Green */
    {.r = 0.0, .g = 1.0, .b = 0.5}, /* COLOR_Mint */
    {.r = 0.0, .g = 1.0, .b = 1.0}, /* COLOR_Cyan */
    {.r = 0.0, .g = 0.5, .b = 1.0}, /* COLOR_Azure */
    {.r = 0.0, .g = 0.0, .b = 1.0}, /* COLOR_Blue */
    {.r = 0.5, .g = 0.0, .b = 1.0}, /* COLOR_Purple */
    {.r = 1.0, .g = 0.0, .b = 1.0}, /* COLOR_Pink */
    {.r = 1.0, .g = 0.0, .b = 0.5}  /* COLOR_Rose */
};

static RGB_COLOR_PCT pixel_colors_pct_S[ RGB_LED_COUNT ];       /* Saved color for each pixel */
static RGB_COLOR_24BIT pixel_colors_24bit_S[ RGB_LED_COUNT ];   /* Converted color for each pixel */
static UINT8 pixel_tx_buffer_u8[ RGB_LED_COUNT * 3 ];           /* Entire LED pixel buffer to send */

static rmt_channel_handle_t RGB_channel_handle = NULL;
static rmt_encoder_handle_t RGB_encoder_handle = NULL;

static RGB_LED_TYPE_PARAMS RGB_LED_params_S;

/*~*~*~*~*~*~*~*~*~*~*~*~*~*~*~*~*~*~*~*~*~*~*~*~*~*~*~*~*~*~*~*~*~*~*~*~*~*~*~*/
/*][ Function Definitions ][~*~*~*~*~*~*~*~*~*~*~*~*~*~*~*~*~*~*~*~*~*~*~*~*~*~*/
/*~*~*~*~*~*~*~*~*~*~*~*~*~*~*~*~*~*~*~*~*~*~*~*~*~*~*~*~*~*~*~*~*~*~*~*~*~*~*~*/
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

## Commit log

2023-06-18 Began porting to ESP32-C3
    Currently only a flashing lights demo using GPIO4 as the LED strip data out pin.
2024-02-10 Enhancement #1,"Add button functionality"
    Created the initial header file and related button types.
    button.h
    * Added
2024-02-11 Enhancement #1,"Add button functionality"
    Created source file for button functionality, minor updates in related files.
    * Prefixed global functions with "extern"
    * Added timer values for debounce, hold, repeat
    button.c
    * Implemented majority of behaviour outlined in button.h
    lib_includes.h
    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
2024-02-17 Enhancement #1,"Add button functionality"
    Added button check and button string functionality.
    * Variable name fix for clarity
    * Implemented button event check
    * Implemented button string conversion
    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
    [button.c]
2024-02-18 Enhancement #1,"Add button functionality"
    Fixed typo
    [button.c]
2024-02-18 Enhancement #1,"Add button functionality"
    Added the messaging calls into the button event sending function.
    * Replaced TODO items with messaging calls
    lib_types.h
    * Re-added 'new event' enum missed by merge conflict
    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
    [button.c]
2024-05-11 Enhancement #2,"Implement real time clock"
    Initial function signatures for the RTC functionality. For now, the only requirement is being able to read to and from a time.h time struct. Interfacing with the hardware will require the use of a ma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
2024-05-11 Enhancement #2,"Implement real time clock"
    Basic outline for RTC functions. Defined PCF85263A i2c addresses in the RTC header file.
    rtc.h
    - Added 7 and 8 bit addresses
    rtc.c
    - Expanded upon initial function prototypes
2024-05-20 Enhancement #4,"Create i2c access controls"
    Added an existing solution for the i2c access issues present in the esp-idf (https://github.com/ropg/i2c_manager)
2024-05-20 Enhancement #2,"Implement real time clock"
    Re-exported the word clock schematic and added it to the project.
2024-05-20 Enhancement #2,"Implement real time clock"
    Added i2c manager functions to the rtc module.
2024-07-14 Enhancement #2,"Implement real time clock"
    Completed testing required for initial RTC implementation:
    - Conversion between time structs and RTC registers are correct.
    - "i2c_manager" component removed, using new ESP-IDF i2c driver. Tested to work.
    - RTC time is set properly.
    - RTC time remains during power-off, proving battery backup works.
    - Properly initializes the button GPIO pins
    - Disabled the builtin M5Stack button due to stuck pin / other issue (TBD)
    main.c
    - Converted the RGB LED task to a generic testing task
    - Implemented the new ESP-IDF I2C driver in favor of the wrapped legacy driver (via i2c_manager).
    - Added log statements
    - Fixed some logical errors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
    [button.c, main.c, rtc.c]
2024-11-02 (No Ticket) Adding Electronics Files
    - Added Gerber files
    - Added top and back renders (redid these, KiCad 6 not supported)
    - Added empty ReadMe for instructions and BOM
    [ESP32C3_WordClock-B_Cu.gbl, ESP32C3_WordClock-B_Mask.gbs, ESP32C3_WordClock-B_Paste.gbp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]
2024-11-02 (No Ticket) Adding Electronics Files
    - Added repo QR code used on the PCB
    - Added BOM .csv file
    [ESP32C3_WordClock_BOM.csv]
2024-11-02 (No Ticket) Adding Mechanical Files
    - Added .STEP files for all mechanical parts
    - Added images / renders
    - Added blank readme file
    [Generic_Backplate.STEP, Generic_Body_NoText.STEP, Generic_Body_NoText.STL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]
2024-11-03 (No Ticket) Adding Mechanical Files
    - Added clock creation scripts and readme.
    [make_clock_body.scad, parts_list.csv]
